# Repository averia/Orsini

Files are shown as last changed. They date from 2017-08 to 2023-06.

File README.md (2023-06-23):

Orsini
======

An atmel328p-pu with Midi in-thru-out, 6 potentiometers and a DAC out.
The six potentiometers have a minijack switch that can be controlled by CV.

orsini

Videos David Ghosting
- [Video 1](https://youtu.be/K4ag43L7bm8)

Arduino sketches

- [MidiVox](https://github.com/averia/Orsini/tree/master/software/MidiVox_Orsini)
   scketch adapted from Narbotic Midivox
- [ORSINI_ARPEGGIO](https://github.com/averia/Orsini/tree/master/software/ORSINI_ARPEGGIO)

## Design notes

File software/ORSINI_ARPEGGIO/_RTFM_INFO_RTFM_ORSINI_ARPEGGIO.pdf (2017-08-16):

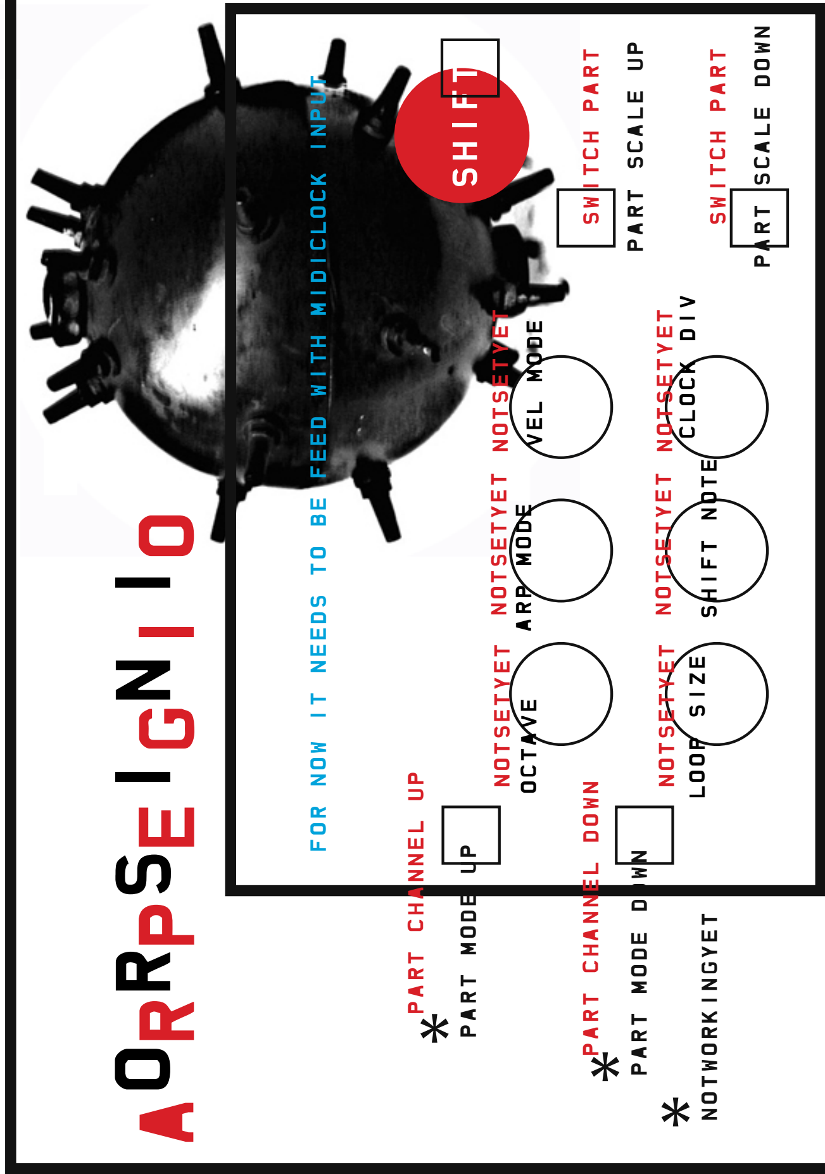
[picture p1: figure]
OCTAVE ARP MODE VEL MODE; LOOP SIZE SHIFT NOTE CLOCK DIV; PART CHANNEL UP; NOTSETYET NOTSETYET NOTSETYET; PART MODE UP; SWITCH PART; PART SCALE UP; PART SCALE DOWN; PART CHANNEL DOWN *; PART MODE DOWN; NOTWORKINGYET; SHIFT; ORSINI ARPEGIO

FOR NOW IT NEEDS TO BE FEED WITH MIDICLOCK INPUT

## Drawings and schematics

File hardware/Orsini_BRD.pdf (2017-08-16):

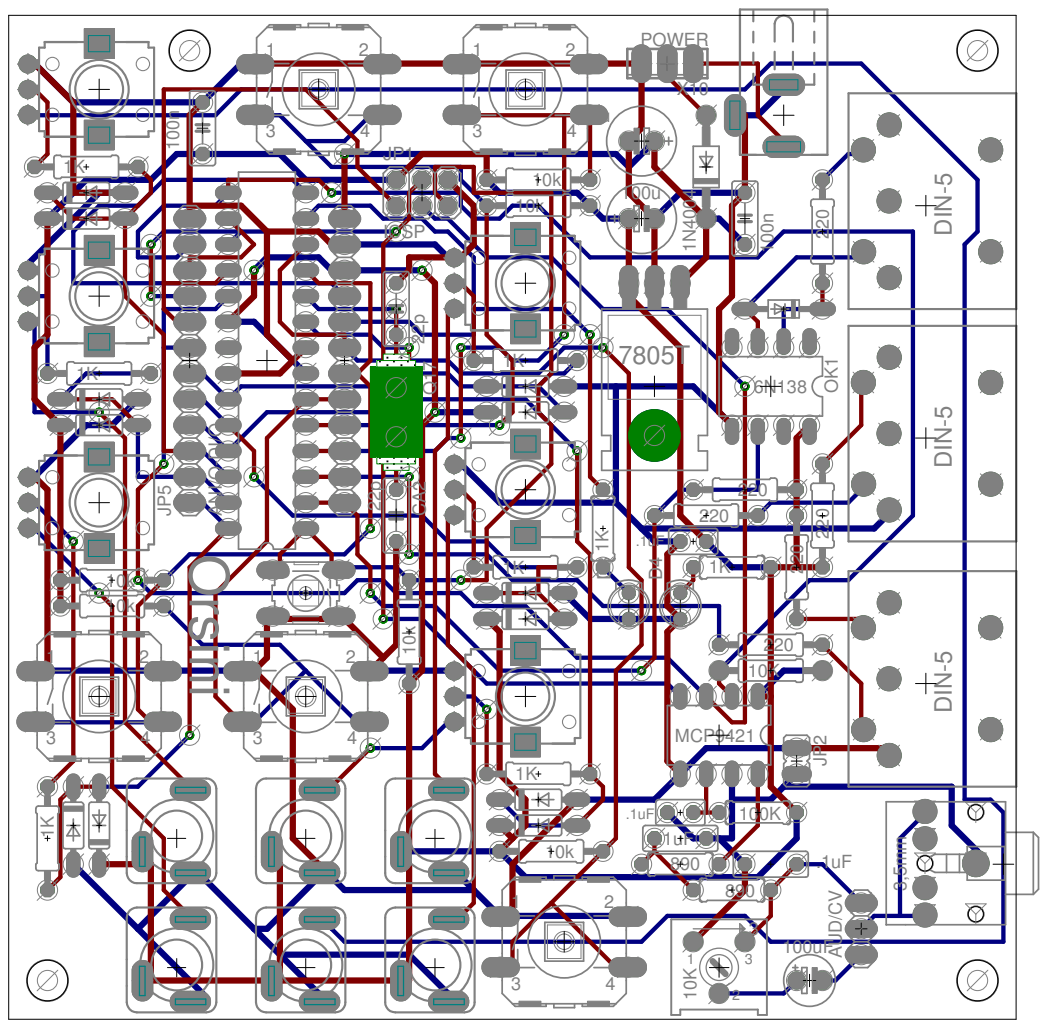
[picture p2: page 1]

DIN-5 DIN-5 DIN-5 3,5mm 1 2 3 4 1 2 3 4 1 2 3 4 1 2 3 4 1 2 3 4 2 1 4 3 3 1 2 3 Orsini Q17 X10 CA2 JP1 D3 D4 OK1 JP5 JP2 7805T 10k 100n 100u 100u 1N4004 POWER 22p 22p 100n ICSP 220 220 220 220 22220 0 890 .1uF 1K .1uF MCP9421 100uF 100K AUD/CV 1K 10K .1uF10K 890 .1uF 6N138 10k 10k 10k 10k ANI/O-DI/O 1K1K1K 1K1K 1K 10k

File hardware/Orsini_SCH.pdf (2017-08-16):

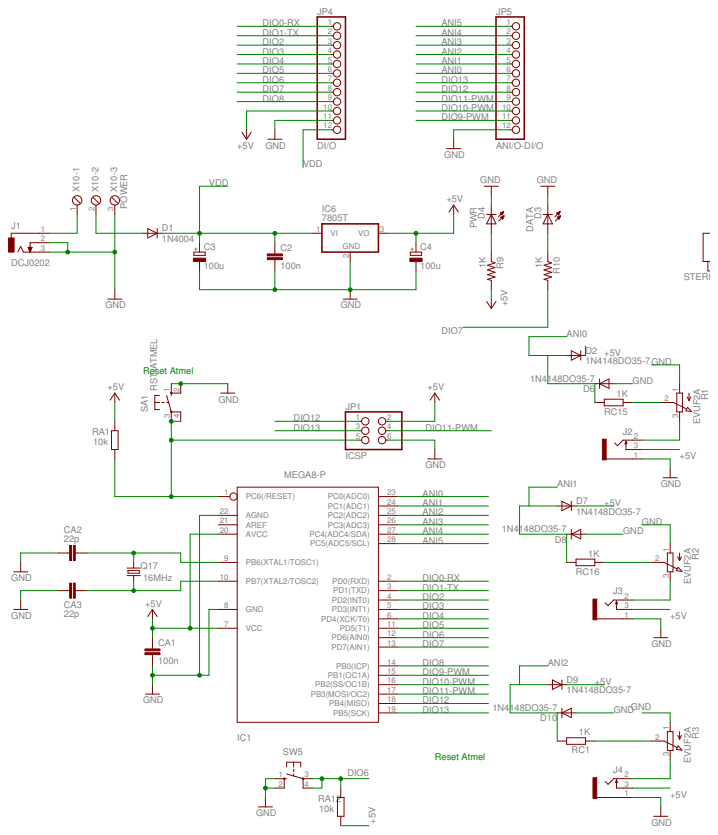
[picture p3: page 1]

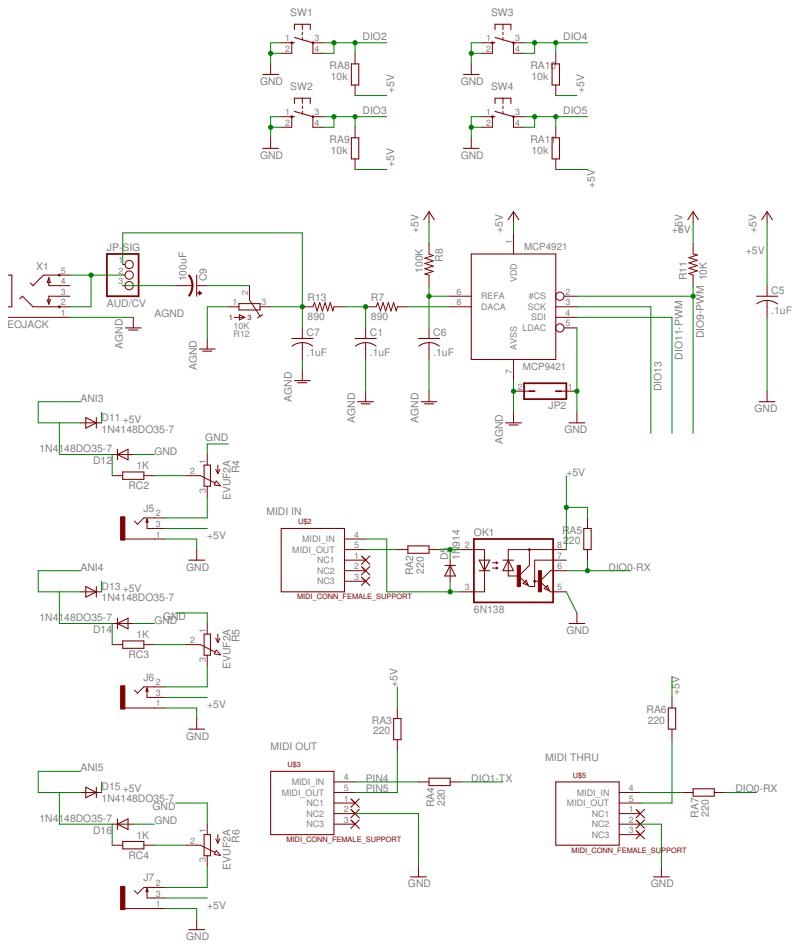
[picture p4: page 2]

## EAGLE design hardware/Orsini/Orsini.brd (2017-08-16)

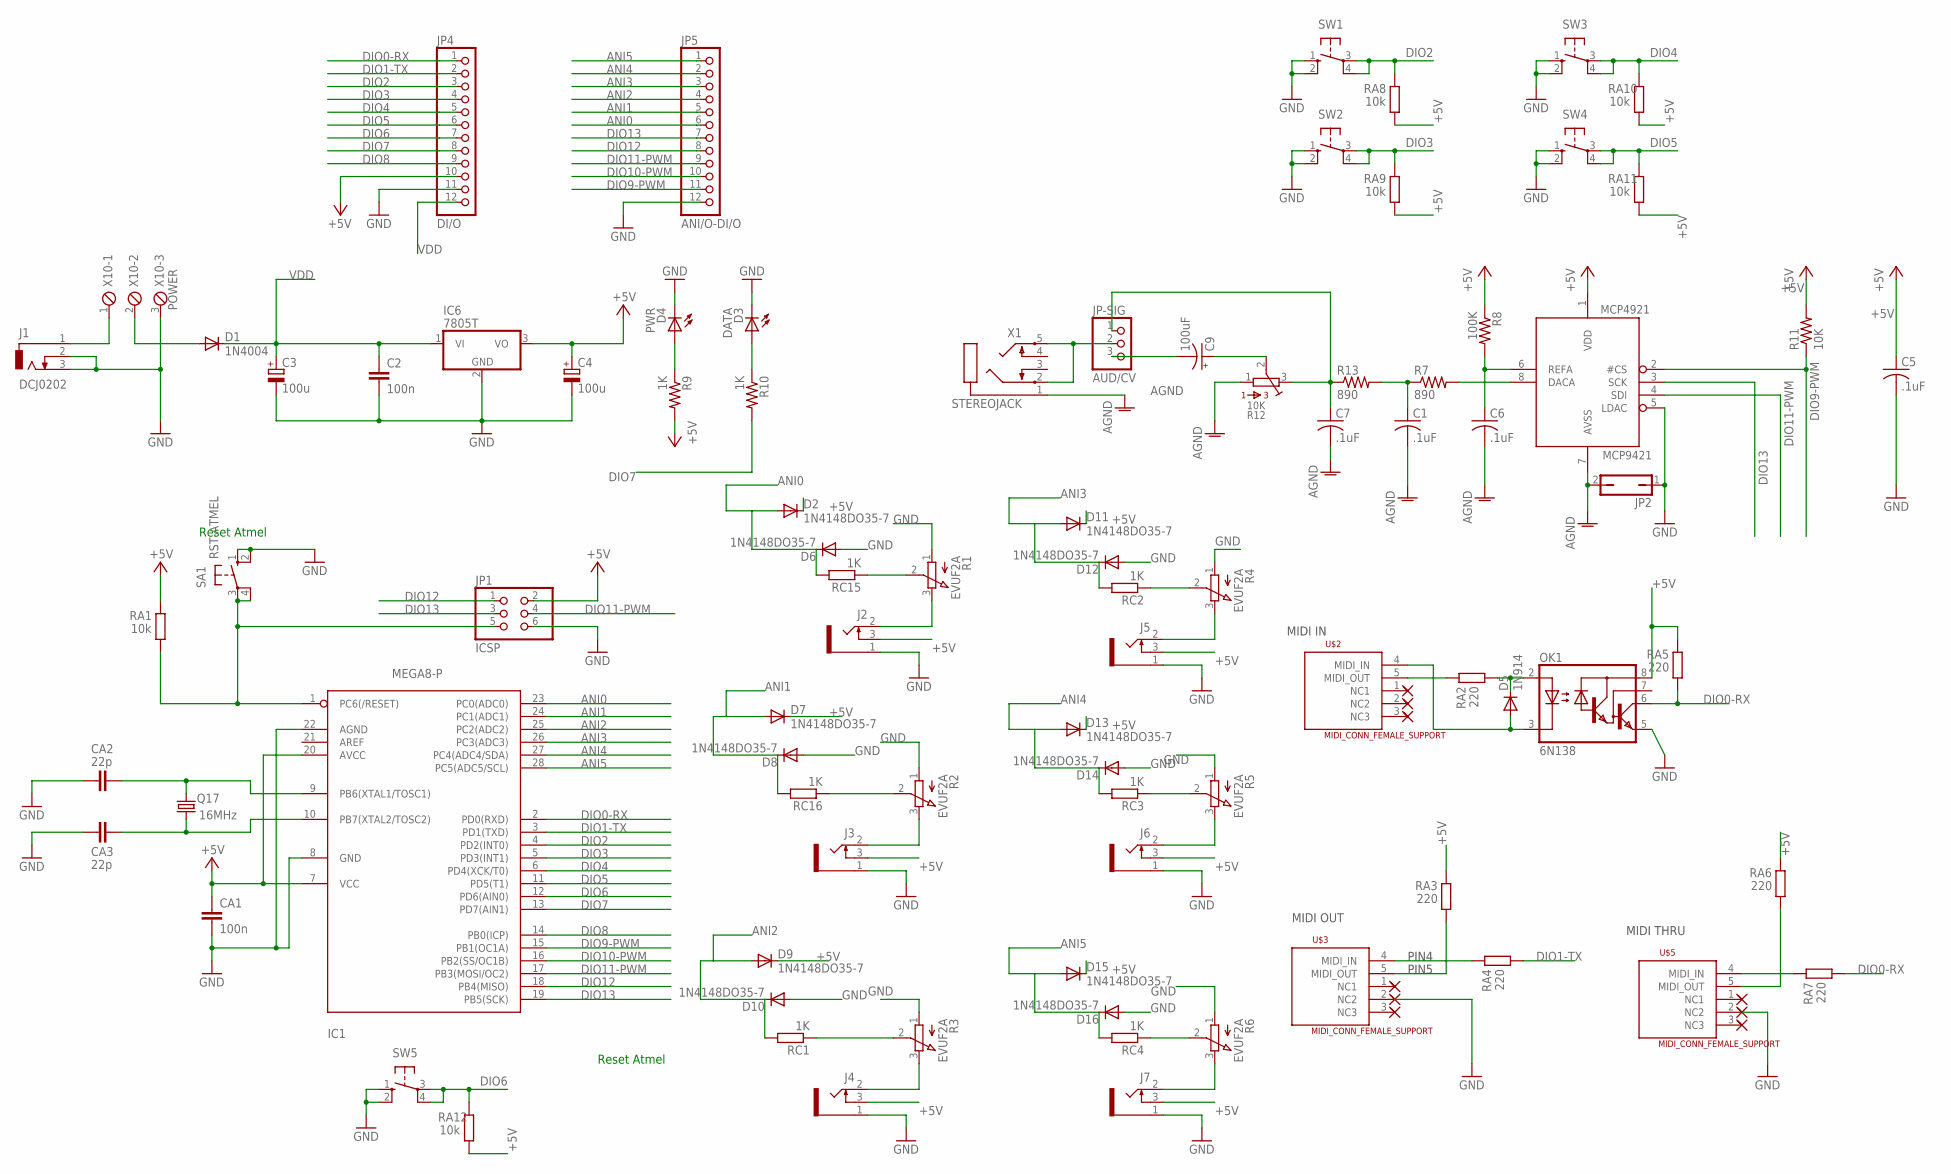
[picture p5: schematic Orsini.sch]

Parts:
C1, C7: .1uF; C050-025X075
C2: 100n; C050-025X075
C3, C4: 100u; E2,5-7
C5, C6: .1uF; C025-025X050
C9: 100uF; E2,5-5
CA1: 100n; C050-025X075
CA2, CA3: 22p; C050-025X075
D1: 1N4004; DO41-10
D2, D6, D7, D8, D9, D10, D11, D12, D13, D14, D15, D16: 1N4148DO35-7; DO35-7
D3: DATA; LED4MM
D4: PWR; LED4MM
D5: 1N914; DO34-7
IC1: MEGA8-P; DIL28-3
IC6: 7805T; TO220H
J1: DCJ0202
J2, J3, J4, J5, J6, J7: 1502_03SLOTTED; 1502_03_SLOTTED
JP1: ICSP; 2X03
JP2: JP1Q; JP1
JP4: DI/O; 1X12
JP5: ANI/O-DI/O; 1X12
JP-SIG: AUD/CV; 1X03
MCP4921: MCP9421; DIL08
OK1: 6N138; DIL08
Q17: 16MHz; HC49/S
R1, R2, R3, R4, R5, R6: EVUF2A; EVUF
R7, R13: 890; 0207/7
R8: 100K; 0207/7
R9, R10: 1K; 0207/7
R11: 10K; 0207/10
R12: 10K; 3386F
RA1, RA8, RA9, RA10, RA11, RA12: 10k; 0207/10
RA2, RA3, RA4, RA5, RA6, RA7: 220; 0207/10
RC1, RC2, RC3, RC4, RC15, RC16: 1K; 0207/10
SA1: RST-ATMEL; B3F-10XX
SW1, SW2, SW3, SW4, SW5: 40-XX; B3F-40XX
U$2, U$3, U$5: MIDI_CONN_FEMALE_SUPPORT; DIN_5_FEMALE_SUPPORT
X1: STEREOJACK; STX3001
X10: POWER; 3POL254

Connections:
56: D5.C, OK1.2 (A), RA2.2
1235: RA3.2, U$3.5 (MIDI_OUT)
+5V: C4.+, C5.1, CA1.1, D2.C, D7.C, D9.C, D11.C, D13.C, D15.C, IC1.7 (VCC), IC1.20 (AVCC), IC6.3 (VO), J2.3, J3.3, J4.3, J5.3, J6.3, J7.3, JP1.2, JP4.10, MCP4921.1 (VDD), OK1.8 (VCC), R8.1, R9.2, R11.2, RA1.1, RA3.1, RA5.1, RA6.1, RA8.2, RA9.2, RA10.2, RA11.2, RA12.2
AGND: C1.2, C6.2, C7.2, JP2.2, MCP4921.7 (AVSS), R12.1, X1.1
ANI0: D2.A, D6.C, IC1.23 (PC0(ADC0)), JP5.6, RC15.2
ANI1: D7.A, D8.C, IC1.24 (PC1(ADC1)), JP5.5, RC16.2
ANI2: D9.A, D10.C, IC1.25 (PC2(ADC2)), JP5.4, RC1.2
ANI3: D11.A, D12.C, IC1.26 (PC3(ADC3)), JP5.3, RC2.2
ANI4: D13.A, D14.C, IC1.27 (PC4(ADC4/SDA)), JP5.2, RC3.2
ANI5: D15.A, D16.C, IC1.28 (PC5(ADC5/SCL)), JP5.1, RC4.2
DIO0-RX: IC1.2 (PD0(RXD)), JP4.1, OK1.6 (VO), RA5.2, RA7.2
DIO1-TX: IC1.3 (PD1(TXD)), JP4.2, RA4.2
DIO2: IC1.4 (PD2(INT0)), JP4.3, RA8.1, SW1.3, SW1.4 (P1)
DIO3: IC1.5 (PD3(INT1)), JP4.4, RA9.1, SW2.3, SW2.4 (P1)
DIO4: IC1.6 (PD4(XCK/T0)), JP4.5, RA10.1, SW3.3, SW3.4 (P1)
DIO5: IC1.11 (PD5(T1)), JP4.6, RA11.1, SW4.3, SW4.4 (P1)
DIO6: IC1.12 (PD6(AIN0)), JP4.7, RA12.1, SW5.3, SW5.4 (P1)
DIO7: IC1.13 (PD7(AIN1)), JP4.8, R10.2
DIO8: IC1.14 (PB0(ICP)), JP4.9
DIO9-PWM: IC1.15 (PB1(OC1A)), JP5.11, MCP4921.2 (#CS), R11.1
DIO10-PWM: IC1.16 (PB2(SS/OC1B)), JP5.10
DIO11-PWM: IC1.17 (PB3(MOSI/OC2)), JP1.4, JP5.9, MCP4921.4 (SDI)
DIO12: IC1.18 (PB4(MISO)), JP1.1, JP5.8
DIO13: IC1.19 (PB5(SCK)), JP1.3, JP5.7, MCP4921.3 (SCK)
GND: C2.2, C3.-, C4.-, C5.2, CA1.2, CA2.2, CA3.2, D3.A (C), D4.A (C), D6.A, D8.A, D10.A, D12.A, D14.A, D16.A, IC1.8 (GND), IC1.22 (AGND), IC6.2 (GND), J1.2, J1.3, J2.1, J3.1, J4.1, J5.1, J6.1, J7.1, JP1.6, JP2.1, JP4.11, JP5.12, MCP4921.5 (LDAC), OK1.5 (GND), R1.1 (A), R2.1 (A), R3.1 (A), R4.1 (A), R5.1 (A), R6.1 (A), SA1.1 (S), SA1.2 (S1), SW1.1 (S), SW1.2 (S1), SW2.1 (S), SW2.2 (S1), SW3.1 (S), SW3.2 (S1), SW4.1 (S), SW4.2 (S1), SW5.1 (S), SW5.2 (S1), U$3.2 (NC2), U$5.2 (NC2), X10.3
unnamed: J1.1, X10.1
unnamed: IC1.1 (PC6(/RESET)), JP1.5, RA1.2, SA1.3, SA1.4 (P1)
unnamed: R1.2 (S), RC15.1
unnamed: D1.A, X10.2
unnamed: CA2.1, IC1.9 (PB6(XTAL1/TOSC1)), Q17.2
unnamed: CA3.1, IC1.10 (PB7(XTAL2/TOSC2)), Q17.1
unnamed: J2.2, R1.3 (E)
unnamed: RA4.1, U$3.4 (MIDI_IN)
unnamed: RA6.2, U$5.5 (MIDI_OUT)
unnamed: R2.2 (S), RC16.1
unnamed: J3.2, R2.3 (E)
unnamed: R3.2 (S), RC1.1
unnamed: RA7.1, U$5.4 (MIDI_IN)
unnamed: RA2.1, U$2.5 (MIDI_OUT)
unnamed: MCP4921.8 (DACA), R7.2
unnamed: JP-SIG.2, X1.2, X1.5
unnamed: C7.1, JP-SIG.1, R12.3, R13.1
unnamed: C6.1, MCP4921.6 (REFA), R8.2
unnamed: C1.1, R7.1, R13.2
unnamed: C9.-, JP-SIG.3
unnamed: D3.K (A), R10.1
unnamed: J4.2, R3.3 (E)
unnamed: R4.2 (S), RC2.1
unnamed: R5.2 (S), RC3.1
unnamed: D4.K (A), R9.1
unnamed: J5.2, R4.3 (E)
unnamed: J6.2, R5.3 (E)
unnamed: J7.2, R6.3 (E)
unnamed: R6.2 (S), RC4.1
unnamed: C9.+, R12.2
PIN5: D5.A, OK1.3 (C), U$2.4 (MIDI_IN)
VDD: C2.1, C3.+, D1.C, IC6.1 (VI), JP4.12

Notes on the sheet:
Reset Atmel
PIN4
PIN5
MIDI IN
MIDI OUT
MIDI THRU

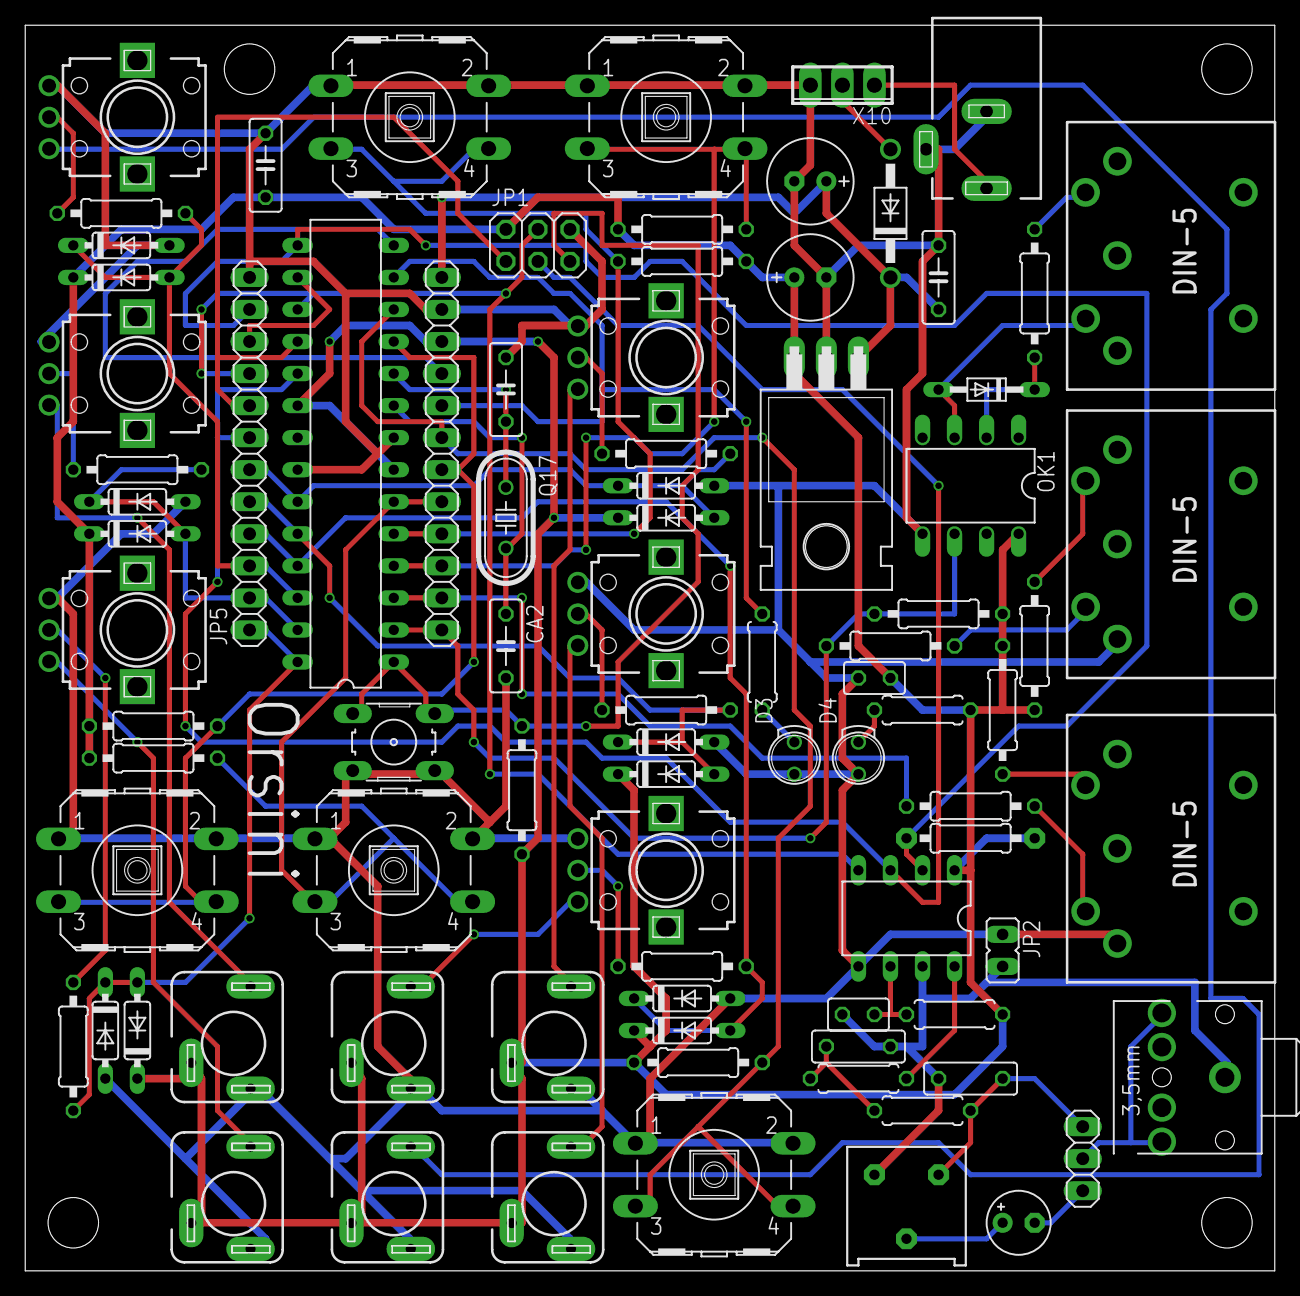
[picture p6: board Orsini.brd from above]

Board: 4 copper layers, 99.0 x 98.7 mm, 86 parts (0 on the bottom side), 57 nets.

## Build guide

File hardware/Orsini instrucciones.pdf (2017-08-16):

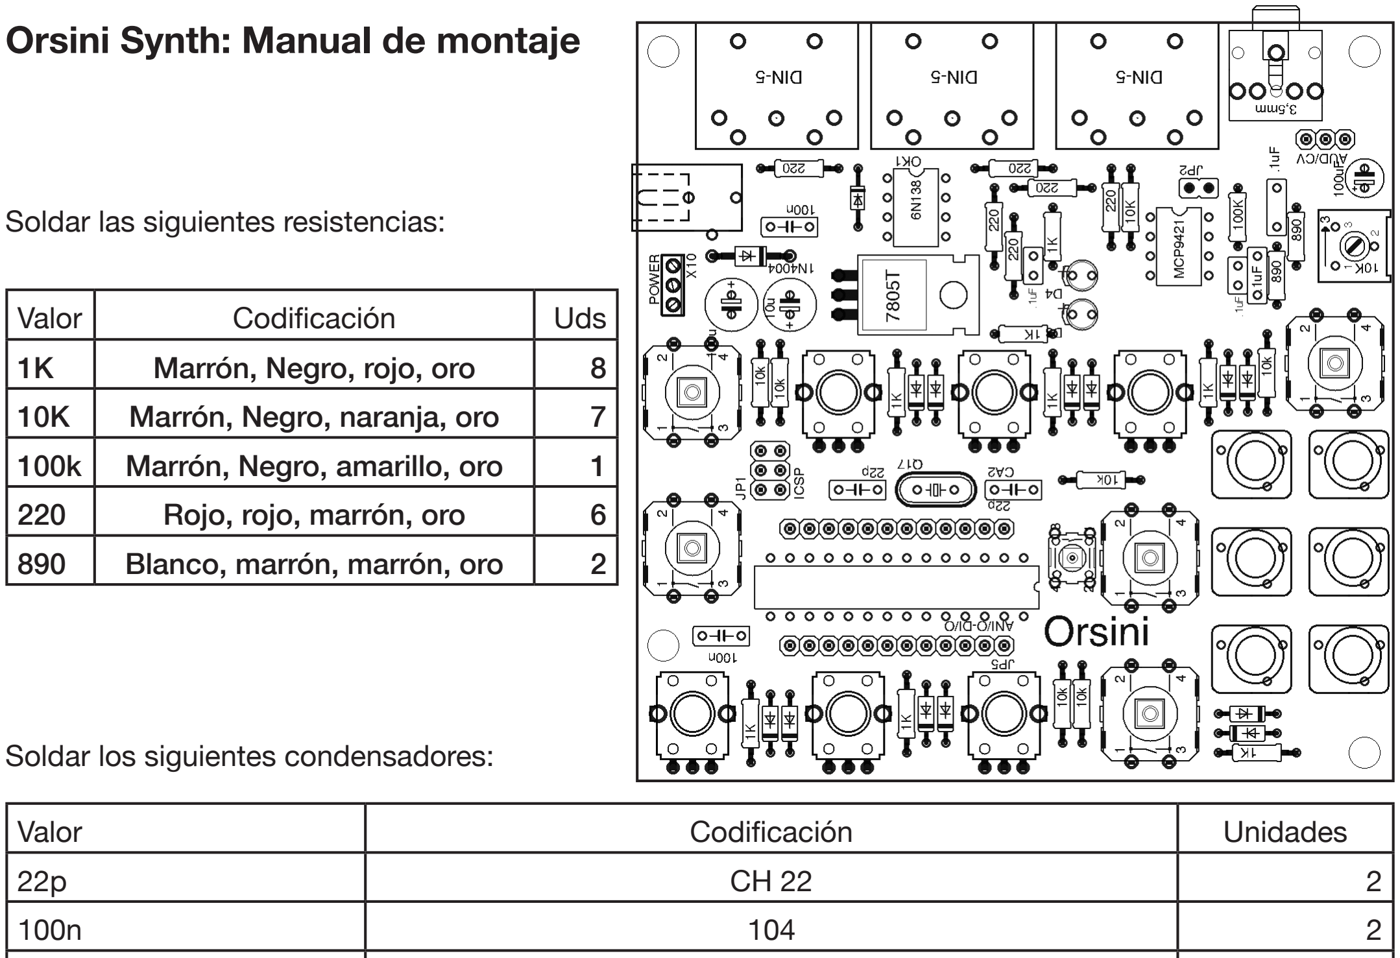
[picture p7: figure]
Valor; Codificación; Uds; Marrón, Negro, rojo, oro; Marrón, Negro, naranja, oro; Marrón, Negro, amarillo, oro; Rojo, rojo, marrón, oro; Blanco, marrón, marrón, oro; Orsini Synth: Manual de montaje; Soldar las siguientes resistencias:; Soldar los siguientes condensadores:; Unidades

1uF (Dibujo pequeño) | 104 | 2
1uF Poly (Dibujo grande) | WIMA 0.1 | 2
10uF | 10uF (!!Atención a la polaridad!!) | 2
100uF | 100uF (!!Atención a la polaridad!!) | 1

Soldar los siguientes diodos:
Valor | Codificadión | Unidades
1n4148 | 4148 (!!Atención a la polaridad!!) | 13
1n4004/1n4007 | 1n4007 (!!Atención a la polaridad!!) | 1

Soldar un trozo de metal en JP2 para puentear la tierra analógica con la tierra digital.
Soldar los leds en su sitio vigilando la polaridad.
Soldar los Pines: JP1 ICSP, Power, Audio/CV. Soldar el reloj de 16.000f.
Colocar los zocalos en su posicion, vigilar muesca y dibujo.
Colocar los pulsadores, el potenciometro de placa de 10k y los 6 potenciometros de 10k. Colocar el conector de corriente, el minijack stereo (Cinco patas) y los minijack mono (Tres patas). Los Din-5 (midi) cortar antes con alicates la parte de atras.
Colocar los jumpers en el power en los dos pines de arriba y en audio o cv.
Colocar los integrados en su sitio vigilando las muescas.

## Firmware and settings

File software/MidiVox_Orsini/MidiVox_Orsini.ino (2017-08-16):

#include <Midi.h>

/***********************************************************************************
 *   HEALER MIDI SYNTH v1.0
 *         written for use with Arduino MidiVox - http://narbotic.com/kits/midivox
 *         based on Arduino Piano Squealer by Marc Nostromo - http://bit.ly/2xrZn5
 *         requires Arduino Midi Library by Tymm Twillman   - http://bit.ly/a6CDpY	
 *
 *   NOTES:
 *    - responds to MIDI note values 0-84
 *    - synth parameters are mapped to MIDI control like so:
 *
 *         CC#____Parameter______
 *          0_____Waveform Select  
 *          1_____Filter Resonance
 *          2_____Filter Cutoff
 *          3_____Filter Type
 *          4_____Filter Envelope (set to 0 to disable)
 *          5_____Wave Loop/Truncate
 *          6_____Attack Time
 *          7_____Release Time
 *          
 ***********************************************************************************/
 
#include <EEPROM.h>
#include "MIDISetup.h"
#include <Bounce.h>

#define WaveFormSel 0
#define FiltRes 1
#define FiltCutOff 2
#define FilterType 3
#define FilterEnvelope 4
#define WaveLoop 5
#define AttackTime 6
#define ReleaseTime 7

// Switches Definition
int waveFormSw1 = 2;
int waveFormSw2 = 3;
int filtTypeSw1 = 4;
int filtTypeSw2 = 5;
// Potentiometer Definition
int filtResPot = 0;
int cutOffPot = 1;
int filtEnvPot = 2;
int waveLoopPot = 3;
int attackPot = 4;
int relTimePot = 5;

long debounce= 200; // Debounce Time in ms

// Counter for the Switches
int cntWFsw=0;
int cntFTsw=0;

Bounce bWFsw1 = Bounce (waveFormSw1, debounce);
Bounce bWFsw2 = Bounce (waveFormSw2, debounce);
Bounce bFTsw1 = Bounce (filtTypeSw1, debounce);
Bounce bFTsw2 = Bounce (filtTypeSw2, debounce);

int ledValue = LOW;

void(* resetFunc) (void) = 0;               //declare reset function @ address 0

void setup(){

  pinMode(6, INPUT);
  digitalWrite(6, HIGH);
  pinMode(7, OUTPUT);
  digitalWrite(7, LOW);
  pinMode(13, OUTPUT);  // For Led
  digitalWrite(13, ledValue);

  // Set Digital Inputs for Waveform Select without Pull-up
  pinMode(waveFormSw1, INPUT);
  //digitalWrite(waveFormSw1, HIGH);
  pinMode(waveFormSw2, INPUT);
  //digitalWrite(waveFormSw2, HIGH);

  // Set Digital Inputs for Filter Type without Pull-up
  pinMode(filtTypeSw1, INPUT);
  //digitalWrite(filtTypeSw1, HIGH);
  pinMode(filtTypeSw2, INPUT);
  //digitalWrite(filtTypeSw2, HIGH);


  MIDI_Setup();                           // Set up MIDI data handlers and such
  SynthController_Setup();                // Initialize synth parameters
  Hardware_Setup();                       // Setup the arduino hardware, interrupts,etc..
  loadPresets();			  // Load preset parameters from eeprom

} 

void loop(){

        CCParams_Read();        // Check Switches and Potentiometers and sets the CC Params.
  	MIDI_Read();            // poll for MIDI data
 	
	if ((PIND&B1000000)==0){
	  saveAndReset();
	}  
}

void flashLED(int pause){
	
	PORTD |= (1<<7);     //digitalWrite(LED, HIGH);
	delay(pause);
        PORTD &= ~(1<<7);    //digitalWrite(7, LOW);
	delay(pause);
	PORTD |= (1<<7);     //digitalWrite(LED, HIGH);
	delay(pause);
	PORTD &= ~(1<<7);    //digitalWrite(7, LOW);
}

void saveAndReset(){
	uint8_t val=0;
	int index=0;
	for (index = 0; index <=7; index++){
	val = (presets[index]);
	EEPROM.write(index, val);
	}
	resetFunc();
}

void loadPresets(){  
	unsigned int val=0;
	int index=0;
	for (index = 0; index <=7; index++){
		val = EEPROM.read(index);			// Load a value from EEPROM
		if (val == 255) {					// If a preset hasn't been saved,
			val = presets[index];			// then load the default
		}
			fillParams(index, val);			
		}

	flashLED(100);
}


void CCParams_Read()
{

  // Temporary Variables
  unsigned int val;
    
  // Check WaveForm Select Switches
 if (bWFsw1.update())
 {
   if (bWFsw1.read() == LOW)
   {
     cntWFsw++;
     if (cntWFsw > 5) cntWFsw = 0;
   }
 }
 
 if (bWFsw2.update())
 {
   if (bWFsw2.read() == LOW)
   {
     cntWFsw--;
     if (cntWFsw < 0) cntWFsw = 5;
   }
 }

  val = cntWFsw * 127 /6;

  if (val != presets[WaveFormSel])
  {
    fillParams(WaveFormSel, val);
  }

  // Check Filter Type Switches 
 
 if (bFTsw1.update())
 {
   if (bFTsw1.read() == LOW)
   {
     cntFTsw++;
     if (cntFTsw > 10) cntFTsw = 0;
   }
 }
 
 if (bFTsw2.update())
 {
   if (bFTsw2.read() == LOW)
   {
     cntFTsw--;
     if (cntFTsw < 0) cntFTsw = 10;
   }
 }

  val = cntFTsw *127/10;

  if (val != presets[FilterType])
  {
    fillParams(FilterType, val);
  }
 
   // Check Filter Resonance Potentiometer
  val = map(analogRead(filtResPot),0,1024,0,127);
  if (val != presets[FiltRes])
  {
    fillParams(FiltRes, val);
  }

  // Check Filter CutOff Potentiometer
  val = map(analogRead(cutOffPot),0,1024,0,127);
  if (val != presets[FiltCutOff])
  {
    fillParams(FiltCutOff, val);
  }

  // Check Filter Envelope Potentiometer
  val = map(analogRead(filtEnvPot),0,1024,0,127);
  if (val != presets[FilterEnvelope])
  {
    fillParams(FilterEnvelope, val);
  }
  
  // Check Wave Loop Potentiometer
  val = map(analogRead(waveLoopPot),0,1024,0,127);
  if (val != presets[WaveLoop])
  {
    fillParams(WaveLoop, val);
  }

  // Check Attack Time Potentiometer
  val = map(analogRead(attackPot),0,1024,0,127);
  if (val != presets[AttackTime])
  {
    fillParams(AttackTime, val);
  }

  // Check Release Time Potentiometer
  val = map(analogRead(relTimePot),0,1024,0,127);
  if (val != presets[ReleaseTime])
  {
    fillParams(ReleaseTime, val);
  }
  
}

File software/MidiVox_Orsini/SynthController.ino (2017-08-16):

//SHARP FILTER CUTOFF CHANGES ARE RISKY

#include "SynthEngine.h"

byte lastKeys = 255;
//float velocityVal = 1.0;
int transposeVal = 48; // -3[transpose multiplier] * 12
byte note = 255;

typedef void (*ControllerFunction) (float);

enum ControllerParamStatus {
  CPS_INACTIVE=0,
  CPS_UPDATE,
  CPS_ENVUP,
  CPS_ENVDOWN
};

enum ControllerParameters {
  CP_WAVE_SHAPE = 0,
  CP_WAVE_LOOP,
  CP_FILTER_MIX,
  CP_FILTER_CUT,
  CP_FILTER_RES,
  CP_OUT_GAIN,
  CP_LAST
};

struct params {
  ControllerParamStatus status_ ;
  ControllerFunction update_ ;
  float envelope_ ;
  float current_ ;
  float target_ ;
  float speed_ ;
};

struct patch {
  float attack_;
  float release_;
  float filterEnvelope_ ;
};

struct params controllerParams[CP_LAST];

struct patch controllerPatch;

void SC_SetParam(byte which,float value, bool reset){
  struct params *current=controllerParams+which ;
  current->current_=value ;
  if ((current->status_==CPS_INACTIVE)||(reset)) {
    current->status_=CPS_UPDATE;
    current->envelope_=0 ;  
  }
};

void SC_SetAttack(float attackVal){
  controllerPatch.attack_=attackVal;
};

void SC_SetRelease(float releaseVal){
  controllerPatch.release_=releaseVal;
};

void SC_SetFilterEnvelope(float filtEnvVal){
			controllerPatch.filterEnvelope_ = filtEnvVal;
};

void SC_SetEnvelope(byte which,float target,float time){

  struct params * current = controllerParams + which;
  if (time < 0.001) {
    current -> envelope_= target ;
    current->status_=CPS_UPDATE ;
  } 
  else {
    current -> target_= target ;
    if (target<current->envelope_) {
      float sp=(current->envelope_-target)/time/200.0 ;
      current->speed_=sp ;
      current->status_=CPS_ENVDOWN ;
    } 
    else {
      float sp=(target-current->envelope_)/time/200.0 ;
      current->speed_=sp ;
      current->status_=CPS_ENVUP ;
    }
  }
};

void SynthController_ProcessEnvelopes(){
  struct params * current = controllerParams ;
  for (byte i=0;i<CP_LAST;i++) {
    if (current->status_!=CPS_INACTIVE) {
      float value=current->current_+current->envelope_ ;
      if (value>1.0) value=1.0;
      if (value<0) value=0.0;
      current->update_(value);
      switch(current->status_){
      case CPS_UPDATE:
        current->status_==CPS_INACTIVE ;
        break ;
      case CPS_ENVUP:
        current->envelope_+=current->speed_ ;
        if (current->envelope_>current->target_) {
          current->envelope_=current->target_ ;
          current->status_=CPS_UPDATE ;
        }
        break ;
      case CPS_ENVDOWN:
        current->envelope_-= current -> speed_ ;
        if (current->envelope_< current->target_) {
          current->envelope_= current->target_ ;
          current->status_= CPS_UPDATE ;
        }
        break ;
      }
    };
    current++ ;
  }
};  

void SynthController_Setup(){
  SynthEngine_Setup() ;
  controllerPatch.attack_ = 0.02;
  controllerPatch.release_ = 0.02;
  controllerPatch.filterEnvelope_ = 0.0;

  struct params *current=controllerParams ;

  for (byte i=0;i<CP_LAST;i++) {
    switch(i) {
    case CP_WAVE_SHAPE:
      current->current_= 0.0;
      current->update_= SE_SetShape ;
      break ;
    case CP_WAVE_LOOP:
      current->current_= 1.0;
      current->update_= SE_SetWidth ;
      break ;
    case CP_FILTER_MIX:
      current->current_= 0.0;
      current->update_= SE_SetFilterMix ;
      break ;
    case CP_FILTER_CUT:
      current->current_= 1.0;
      current->update_= SE_SetFilterCut ;
      break ;
    case CP_FILTER_RES:
      current->current_= 0.0;
      current->update_= SE_SetFilterRes;
      break ;
    case CP_OUT_GAIN:
      current->current_= 0.0;
      current->update_= SE_SetOutput;
      break ;
    default:
      current->update_= 0;
      break ;      
    }
    if (current->update_) {
      current->update_(current->current_) ;
    }
    current->status_ = CPS_INACTIVE;
    current->envelope_ = 0;
    current++;
  }
  SC_SetParam(CP_OUT_GAIN,0.0,true);
};

void SynthController_Trigger(byte keys, float filterVal, float attackVal, float releaseVal){
	
	
  //velocityVal = (velocity/float(127-weight));
  //if (velocityVal > 1.0) velocityVal = 1.0;
	
    if (lastKeys!=keys){
		note = keys; 
		lastKeys = keys;
		
	  if (filterVal > 0.0) {
			  if (note < 84){	// notecap could be <255
				  SE_SetNote(note - transposeVal);
				  SC_SetEnvelope(CP_FILTER_CUT, 1.0, filterVal); // if Filter Envelope
				  // FOR VELOCITY - SC_SetEnvelope(CP_OUT_GAIN, velocityVal, attackVal);
				  SC_SetEnvelope(CP_OUT_GAIN, 1.0, attackVal);
			  }
			  else {
				  SC_SetEnvelope(CP_FILTER_CUT, 0.0, filterVal);
				  SC_SetEnvelope(CP_OUT_GAIN,0.0,releaseVal);
			  }
	  }
		
		else{
		if (note < 84){										// notecap could be <255
				  SE_SetNote(note - transposeVal);
				  // FOR VELOCITY - SC_SetEnvelope(CP_OUT_GAIN, velocityVal, attackVal);
				  SC_SetEnvelope(CP_OUT_GAIN, 1.0, attackVal);
			  }
			  else {
				  SC_SetEnvelope(CP_OUT_GAIN,0.0,releaseVal) ;  // CHANGED
			  }
	  }
    }
};
  
